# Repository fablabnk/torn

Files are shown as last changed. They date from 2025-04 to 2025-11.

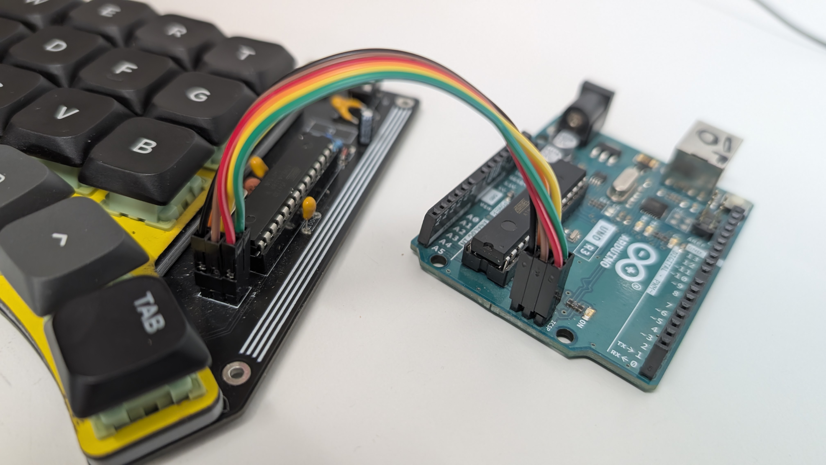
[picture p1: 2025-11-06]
TornFlashGuideICSPPins.jpg

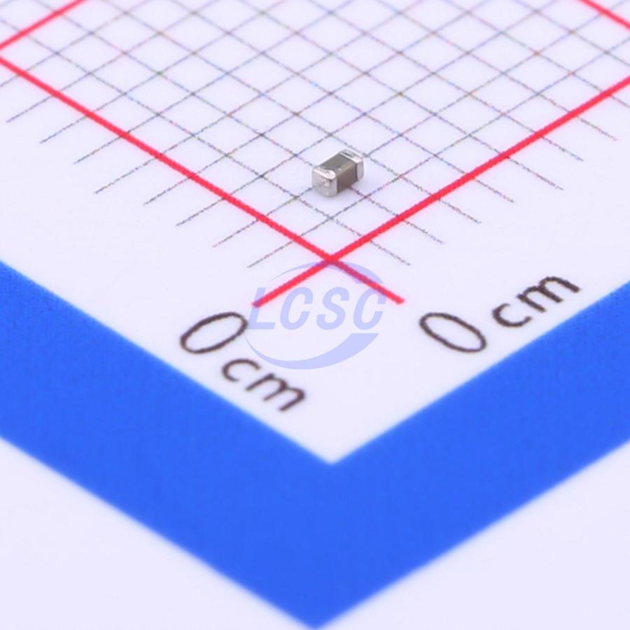
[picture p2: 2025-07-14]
notes/DIYKeyboardPCBA/JLCPCB PCBA Viewer_files/20221230_Samsung-Electro-Mechanics-CL05A105KA5NQNC_C5292_002.jpg

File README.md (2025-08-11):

This is the 42 Berlin fork of the original torn v3 project. We would like to make this project available to anyone in the school who has interest, but first we want to reliably be able to build the project and document any extra steps here.

# Project Status

- Both sides of the keyboard work and can be configured using QMKVia
- Waiting on new PCBs (USB Mini)
- QMKVia flashed (instead of previously just QMK default without Via)

# Next Steps

## Assemble one of the new just Urs and I
- 28th July
- document any remaining issues

## Open project for more people to get involved (at Teatime event Aug 13th)
	- leave the prototype keyboard in cafe and showcase at teatime event on 13th August
	- people can register to the projet via google form
	- order parts and PCBs based on number of registrations
	- set build day (or two days)

## Hosting 'workshop' where we build three or four more

one big day - or a couple of 3 or 4 hour events
deadline

0. Introduction to custom keyboards
- do we have a keyboard 'nerd' we could reach out to and include in the group?
1. Soldering
- solder everything or focus on microcontroller/display first
2. Flashing QMK/Via
- keep dedicated flashing setup on hand
- note that this was done by the previous group so we need to figure out how it works and documents
3. Configuration
- 
4. Case

# To Do

- Get LEDs working - LEDs are apparently not configured in the current QMK firmware
	- Define the correct pin assignments for the LEDs in config.h.
	- Implement the appropriate LED control functions in your keymap or keyboard .c file, such as led_set_user() for lock indicators or custom code for other uses.

- Solve display glitching issue
	- probably hardware related as we tested with another half which doesn't glitch

- add this line to build-guide.md
	- In order to call 'make' the qmk cli has to be installed. Follow the instructions [here](https://docs.qmk.fm/newbs_getting_started).

- Make one default layout that everyone gets at the beginning

# Documented Issues

## Flashing the Bootloader

We have an Arduino set aside in a box to help with flashing the bootloader
The original guide has the right instructions in terms of pinouts, but it's easy to the wiring up, so for 2nd build we should to document better how to wire the pins to the 6-pin header on the keyboard (photo)

## Flashing the Firmware

There were two issues here that diverged from the build guide. We installed all the necessary dependencies and tools in the LabAdmin account on the computer on the left next to the window.

- QMKVia which torn v3 uses is no longer supported. We don't have a solution for this, as the support for it its dropped and requires manual intervention and investigation as mentioned in the author isse https://github.com/rtitmuss/torn/issues/29

- The make command to be run from the qmk_firmware folder is ```make torn:default:flash``` as opposed to the guide. Keyboard must be set to flashing mode.

## Layout Configuration

- A C file is used to configure the keyboard [keymap file](https://github.com/qmk/qmk_firmware/blob/master/keyboards/torn/keymaps/default/keymap.c). This could be improved by adding a wrapper. Any alterations require compiling and flashing to the chip, which could complicate things though

## Button Height

The choice of height of the two reset/boot buttons is important. For the first build we used very flat buttons, only later to discover that they are inaccessible when adding the transparent acrylic layer on top. The solution to this would be to use taller buttons (we have them in different sizes in a kit) and to cut holes in the acrylic layer to allow the buttons to poke through.

## Choice of Case

It helps to consider which case you might build even from the get-go, as it can affect which buttons you choose (see below) and for some cases the switches/keycaps need to be of a certain type.

What we tried to far:
- PCB Case: We noted that there are no .svg files provided for laser cutting the parts, we must create our own from the Kicad projects (base and plate). This requires a few design decisions (indent around USB connector etc)
- HiPro Case: Be aware that there are two variations here for MX or Choc switches

# FAQ

## What is VIA and how does it work?

VIA is a software tool that allows you to dynamically remap keys and configure your keyboard layout in real time—without needing to reflash the firmware each time you want to make a change. Carlo and co didn't get this to work and filed this issue: https://github.com/rtitmuss/torn/issues/29

- Keys are organised in categories - can be character or functions
- Layers at Tip Left
- Keys show both click and hold functions
- If Via doesn't provide the functionality you need, you can alway use QMK syntax by using the "Any" wildcard key, which lets you hardcode QMK keycode e.g. LT(2, KC_DEL) which when holding delete will put you in layer 2
- Here is a basic (cheat sheet)[https://docs.qmk.fm/keycodes_basic] for QMK keycodes

One issue we had is how to flash QMKVia, as:
- VIA keymaps are no longer held in the main QMK git repository.
- You will need to either compile a default one, write your own one, or follow the instructions to add the VIA userspace repository.
- See https://docs.qmk.fm/ChangeLog/20240526#migration-of-via-keymaps-to-via-team-control

## What firmware is running on the keyboard now?

QMK default

## How to flash QMK again in order to update the keyboard configuration?

See QMK section of torn build guide: https://github.com/rtitmuss/torn/blob/master/doc/build.md

## What are LEDs for and how to configure them?

Caps Lock, Num Lock, and Scroll Lock

## Are button row of keys even working?

In keymap.c, we can see the real function of these keys in the QWERTY layer
Left:	R_DEL,   KC_LCTL, S_BSPC,  R_DEL
Right:	G_ENT,   L_SPC,   KC_RALT, G_ENT

Note: don't trust keymap.c ASCII, configuration differs (so UP arrow being above DOWN)

Layers do work e.g.
- On left side of keyboard, 1st and 4th key R_DEL
	- performs delete when tapped
	- moves to RAISE layer when held
- On the right side of the keyboard, 2nd key L_SPC 
	- perform space when tapped
	- goes into lower mode when held 

Note: KC_TRNS or _______ means to look down to the next layer for the underlying function of the key

## What are rotary encoders typically used for?

- Scrolling (vertical or horizontal in documents/web pages)
- Undo/redo
- Zoom in/out
- Tab or window switching
- Launching macros or custom shortcuts.

# Remapping

This means editing the QMK keymap.c file within the QMK firmware and reflashing the firmware
https://github.com/qmk/qmk_firmware/blob/master/keyboards/torn/keymaps/default/keymap.c
- we don't want to do this right now!

https://github.com/qmk/qmk_firmware/tree/master/keyboards/torn

// https://github.com/rtitmuss/torn/issues/29

# Via Setup

# Setup your torn keyboard with via

## QMK Setup
 - Set up QMK Firmware including CLI like described [here](https://docs.qmk.fm/newbs_getting_started)
 - In order to get it running on linux I actually had to update my PATH varaiable accordingly (see  'Note on Debian, Ubuntu and their derivatives')

## get External QMK Userspace 
 - Instead of cloning the QMK-Firmware from the github, get the [QMK userspace via](https://github.com/the-via/qmk_userspace_via) repo and use it with the CLI instead.
 - I think one could also get the original firmware and change all the configs accordingly, however this one is already onfigured to work with VIA.

## Flash Torn 
 - Now inside the root folder, use the CLI to either compile:
 `qmk compile -kb torn -km via`
 or directly flash the updated keyboard firmware:
 `qmk flash -kb torn -km via`
 -> in order to flash, i usually have to reconnect the keyboard, wait until the oled shows 'TORN' and go into boot mode: like described [here](https://github.com/fablabnk/torn/blob/master/doc/build.md) in chapter QMK

## Configure using VIA 
 - After successfully flashing, I dis and reconnect the keyboard again and open the [via app](https://www.usevia.app/) in a chromium based browser or the Desktop app, which is available for download [here](https://github.com/the-via/releases/releases/)

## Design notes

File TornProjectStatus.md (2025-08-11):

# Next Steps: First Build of New PCB

With view to hosting a 'workshop' where we build three or four more

1. Soldering
	- take a 

	everything or focus on microcontroller/display first

2. Flashing
	- is flashing process documented
	- bootloader
	- firmware
	- keep dedicated flashing setup on hand
3. Configuration
	- Learning how to use Via
4. Casemaking	

Rotary encoders, primarily used for:
- Scrolling (vertical or horizontal in documents/web pages)
- Undo/redo
- Zoom in/out
- Tab or window switching
- Launching macros or custom shortcuts.

# How Does Via Work
- Keys are organised in categories - can be character or functions
- Layers at Tip Left
- Keys show both click and hold functions

# Next Steps
- meet again at 17:30
- goal to decide on a clear way for configuring the keyboard
- assemble one just Urs and I
- open project for more people to get involved
	- leave the prototype keyboard in cafe and showcase at teatime event on 13th August
	- people can register to the projet via google form
	- order parts and PCBs based on number of registrations
	- set build day (or two days)

# Status
- Two halves basically work
- Display glitches
- Main top three rows of keys work on each side
- Bottom function keys are not properly working
- USB C connector is a pain to solder (considering rolling back to usb mini)

# To Do

- Get LEDs working - LEDs are apparently not configured in the current QMK firmware
	- Define the correct pin assignments for the LEDs in config.h.
	- Implement the appropriate LED control functions in your keymap or keyboard .c file, such as led_set_user() for lock indicators or custom code for other uses.

- Solve display glitching issue
	- probably hardware related as we tested with another half which doesn't glitch

- Add this line to build-guide.md
	- In order to call 'make' the qmk cli has to be installed. Follow the instructions [here](https://docs.qmk.fm/newbs_getting_started).

- Understand why it doesn't (always) connect straight away or wake from sleep - hardware or software issue?

# Questions

## What is VIA?

VIA is a software tool that allows you to dynamically remap keys and configure your keyboard layout in real time—without needing to reflash the firmware each time you want to make a change. Carlo and co didn't get this to work and filed this issue: https://github.com/rtitmuss/torn/issues/29

Issue is that:
- VIA keymaps are no longer held in the main QMK git repository.
- You will need to either compile a default one, write your own one, or follow the instructions to add the VIA userspace repository.
- See https://docs.qmk.fm/ChangeLog/20240526#migration-of-via-keymaps-to-via-team-control

## What firmware is running on the keyboard now?

QMK default

## How to flash QMK again in order to update the keyboard configuration?

See QMK section of torn build guide: https://github.com/rtitmuss/torn/blob/master/doc/build.md

## What are LEDs for and how to configure them?

Caps Lock, Num Lock, and Scroll Lock

## Are button row of keys even working?

In keymap.c, we can see the real function of these keys in the QWERTY layer
Left:	R_DEL,   KC_LCTL, S_BSPC,  R_DEL
Right:	G_ENT,   L_SPC,   KC_RALT, G_ENT

Note: don't trust keymap.c ASCII, configuration differs (so UP arrow being above DOWN)

Layers do work e.g.
- On left side of keyboard, 1st and 4th key R_DEL
	- performs delete when tapped
	- moves to RAISE layer when held
- On the right side of the keyboard, 2nd key L_SPC 
	- perform space when tapped
	- goes into lower mode when held 

Note: KC_TRNS or _______ means to look down to the next layer for the underlying function of the key

# Remapping

This means editing the QMK keymap.c file within the QMK firmware and reflashing the firmware
https://github.com/qmk/qmk_firmware/blob/master/keyboards/torn/keymaps/default/keymap.c
- we don't want to do this right now!

#

https://github.com/qmk/qmk_firmware/tree/master/keyboards/torn

// https://github.com/rtitmuss/torn/issues/29

# Via Setup

# Setup your torn keyboard with via

## QMK Setup
 - Set up QMK Firmware including CLI like described [here](https://docs.qmk.fm/newbs_getting_started)
 - In order to get it running on linux I actually had to update my PATH varaiable accordingly (see  'Note on Debian, Ubuntu and their derivatives')

## get External QMK Userspace 
 - Instead of cloning the QMK-Firmware from the github, get the [QMK userspace via](https://github.com/the-via/qmk_userspace_via) repo and use it with the CLI instead.
 - I think one could also get the original firmware and change all the configs accordingly, however this one is already onfigured to work with VIA.

## Flash Torn 
 - Now inside the root folder, use the CLI to either compile:
 `qmk compile -kb torn -km via`
 or directly flash the updated keyboard firmware:
 `qmk flash -kb torn -km via`
 -> in order to flash, i usually have to reconnect the keyboard, wait until the oled shows 'TORN' and go into boot mode: like described [here](https://github.com/fablabnk/torn/blob/master/doc/build.md) in chapter QMK

## Configure using VIA 
 - After successfully flashing, I dis and reconnect the keyboard again and open the [via app](https://www.usevia.app/) in a chromium based browser or the Desktop app, which is available for download [here](https://github.com/the-via/releases/releases/)

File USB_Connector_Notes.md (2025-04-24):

I want to replace the original 16-pin USB C connector with a mini USB connector

https://www.aliexpress.com/item/1005005298166566.html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

USB_C_GCT_USB4085-Type-C 16 pin Female Connector

A1	GND	Ground
A4	VBUS	Power (5V)
A5	CC1	Configuration Channel 1
A6	D+	USB 2.0 Data+
A7	D-	USB 2.0 Data-
A8	SBU1	Sideband Use 1
A9	VBUS	Power (5V)
A12	GND	Ground
B1	GND	Ground
B4	VBUS	Power (5V)
B5	CC2	Configuration Channel 2
B6	D+	USB 2.0 Data+
B7	D-	USB 2.0 Data-
B8	SBU2	Sideband Use 2
B9	VBUS	Power (5V)
B12	GND	Ground

Mini USB Type B 5-Pin Female Connector

1	VCC	+5VDC Power
2	D-	Data Negative
3	D+	Data Positive
4	ID	Identification (often not connected)
5	GND	Ground

1 3 5
 2 4

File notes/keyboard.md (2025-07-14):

corne cherry v3 bom

# Components Assembled by JLCPCB

42 x D3_SMD_v2 SMD diodes
12 x LED_WS2812B_PLCC4_5.0x5.0mm_P3.2mm
42 x SK6812MINI-E LED
2 x Reset switches - https://www.digikey.com/en/products/detail/c-k/PTS636-SP43-LFS/10071717
Kailh or Mill-Max Hotswap Sockets - guessing

# Components to Self-solder/Install

40 x CherryMX_Hotswap switches (for normal keys)
2 x CherryMX_Hotswap_1.5u switches (for the two larger keys)
2 x MJ-4PP-9 TRS jacks
2 x OLEDs - what kind?
2 x Sparkfun ProMicro V3 microcontrollers
2 x battery packs

Cherry MX Hotswap switches do not need to be soldered to a PCB. Hotswap PCBs are designed to allow switches to be inserted and removed without soldering, thanks to the use of hotswap sockets like Kailh or Mill-Max. These sockets have spring-loaded contacts that make electrical connections with the switch pins when inserted, allowing for easy swapping of switches without the need for soldering

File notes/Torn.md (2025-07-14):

# Torn

Video of the build: https://www.youtube.com/watch?v=7WUTQ30Datw
Build log: https://github.com/rafaeldelboni/buildlogs/blob/main/torn-v3.md
The torn project (through hole corne keyboard): https://github.com/rtitmuss/torn

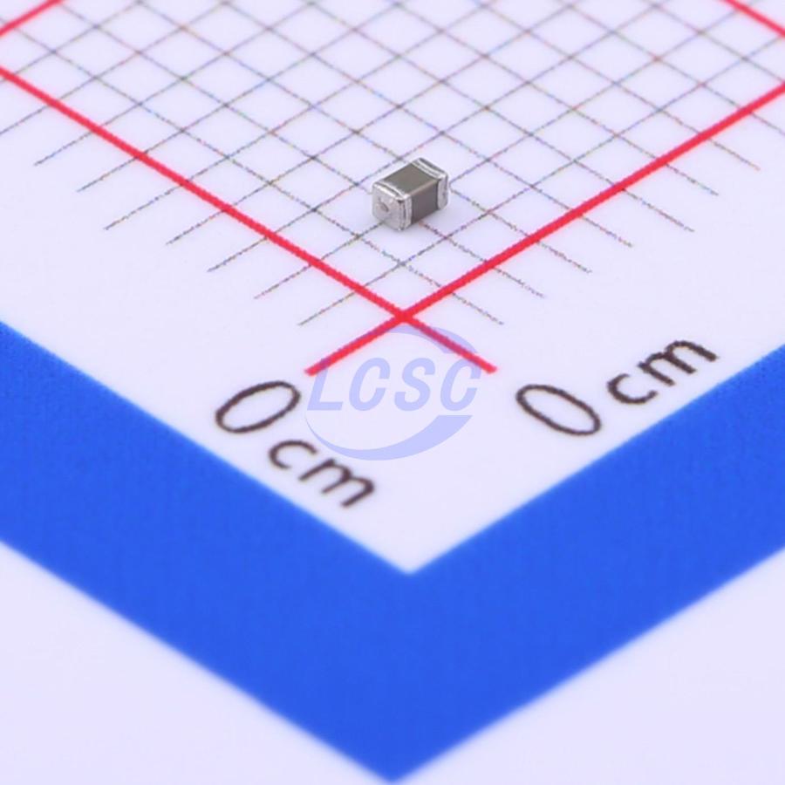
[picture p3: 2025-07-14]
notes/DIYKeyboardPCBA/JLCPCB PCBA Viewer_files/20220823_Samsung-Electro-Mechanics-CL05A106MQ5NUNC_C15525_fr.jpg

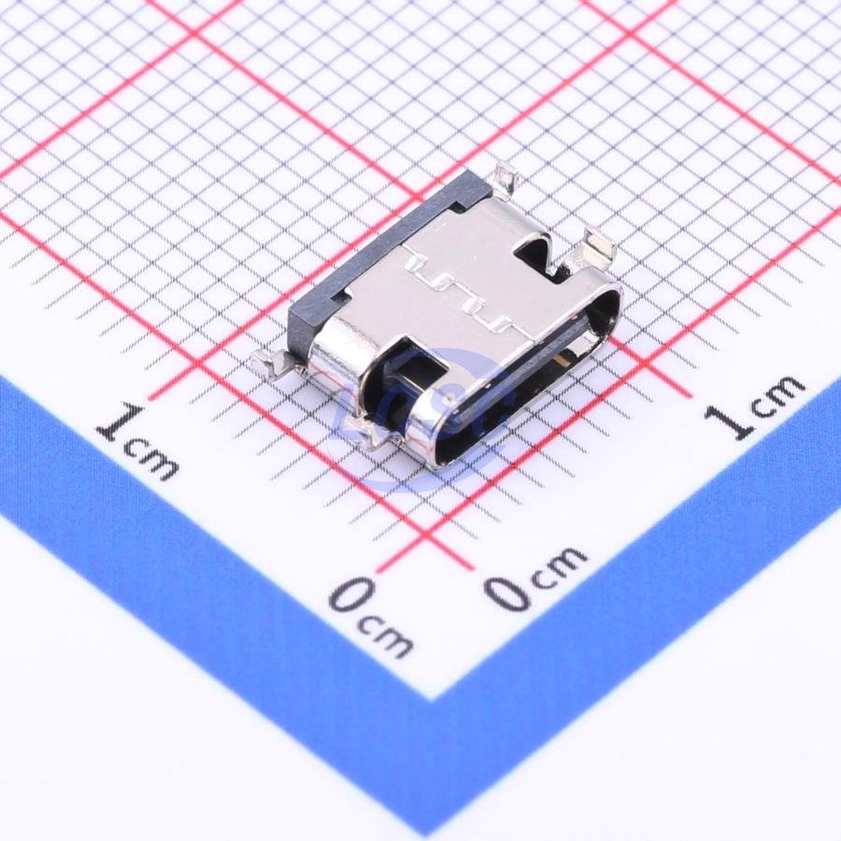
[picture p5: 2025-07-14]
notes/DIYKeyboardPCBA/JLCPCB PCBA Viewer_files/20230121_Korean-Hroparts-Elec-TYPE-C-31-M-13C_C2848620_front.jpg

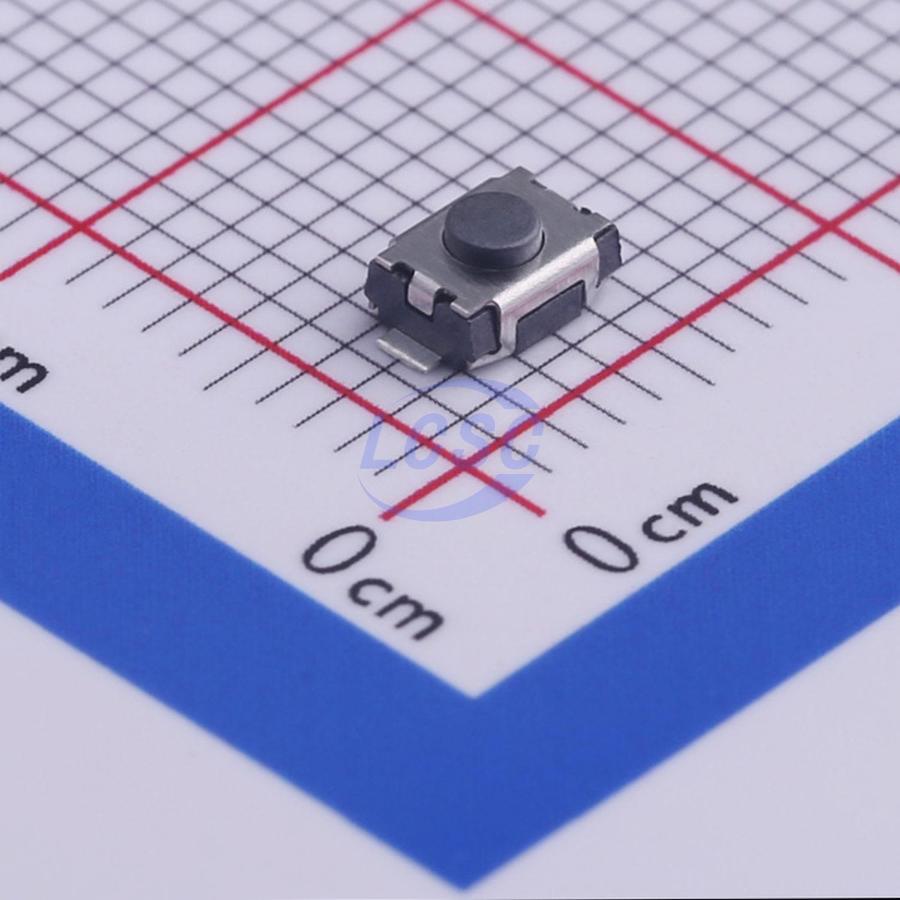
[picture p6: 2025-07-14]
notes/DIYKeyboardPCBA/JLCPCB PCBA Viewer_files/20230118_XUNPU-TS-1088R-02026_C455280_front.jpg

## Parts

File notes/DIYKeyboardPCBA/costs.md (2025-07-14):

Charge Details

    Engineering fee €3.64
    Board €10.27

Economic PCBA PriceSetup Fee €7.27

    Stencil  €1.36
    Components €10.15 (for each keyboard)
    Extended components fee ? €2.73 per Extended Component (of which we currently have 13 such parts)
    SMT Assembly ?

Shipping roughly €20

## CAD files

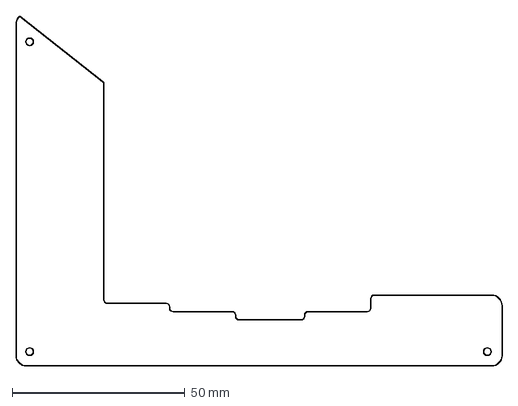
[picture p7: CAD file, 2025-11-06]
case/cover-1to1scale.dxf
140.7 x 101.3 mm

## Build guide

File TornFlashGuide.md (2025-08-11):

Note: maybe first step should be ATMEGA/crystal/caps as show here
https://github.com/rtitmuss/torn/blob/master/doc/bootloader.md

# ICSP header 

We use an Arduino Uno to flash the QMK/via firmware onto the ATMEGA328P chip mounted on the left half of the torn. To do this we connect together the ICSP header

An ICSP (In-Circuit Serial Programming) header is a standardized 6-pin interface on microcontroller boards used to program the microcontroller while it is installed in the circuit. It typically includes pins for power (VCC), ground (GND), reset, clock (SCK), and data lines (MISO and MOSI) for serial communication. 

The ICSP header on both the torn and the Uno is oriented in the same way. When USB ports are facing upwards, the pinout is as follows, where bottom right pin (2) is VCC/5V

https://mischianti.org/arduino-uno-rev-3-high-resolution-pinout-datasheet-and-specs/

5 3 1
6 4 2

The full list of connections is as follows:

ICSP Pin 1 (MISO)	→ ATmega328P Pin 18	(MISO)		COL4		
ICSP Pin 2 (VCC)	→ Power Supply		(5V)					RED
ICSP Pin 3 (SCK)	→ ATmega328P Pin 19	(SCK)		COL3		
ICSP Pin 4 (MOSI)	→ ATmega328P Pin 17	(MOSI)		COL5		
ICSP Pin 5 (RESET)	→ ATmega328P Pin 1	(RESET)					
ICSP Pin 6 (GND)	→ Ground			(GND)					BLACK

Original guide here: https://github.com/rtitmuss/torn/blob/master/doc/bootloader.md
- don't trust it - board is different - take own photos
- why do they not use the Reset pin on the ICSP header, and instead wire a separate connection to Pin 10 of the Uno?

- in short:

# Program the Uno as an In-circuit Serial Programmer (ISP)

// Follow https://www.arduino.cc/en/Tutorial/ArduinoISP#toc5 to program the whole flash memory of the microcontroller, bootloader included.

Skip the whole "How to wire your boards" section - this we will do with our torn later
Tools -> Burn Bootloader !?!?!
3. Tools -> Programmer -> "Arduino as ISP"

In Arduino IDE, select:
1. Tools -> Board -> Arduino Uno
2. Tools -> Port -> e.g. /tty/USB0
3. File -> Examples -> ArduinoISP -> ArduinoISP
4. Upload the sketch to the Uno
5. Connect an 10µF electrolytic capacitor between Arduino RESET and GND pins with the positive (long leg) connected to RESET
6. Connect pin 10 of Arduino to top left pin 5 of torn
7. Connect all other pins of torn ICSP header to their corresponding ICSP pins on the Uno
- Note that we don't need to power the keyboard via USB 
- Power to ATMEGA is provided by ICSP header 
7. Download https://github.com/rtitmuss/USBaspLoader, do `git switch torn` to switch to torn-specific branch 
- Edit Makefile.inc to point to /dev location of the Arduino Uno (check by `ls /dev` before and after connecting)
`PROGRAMMER = -c avrisp -P /dev/cu.usbmodem* -b19200`
In my case it needed to be:
`PROGRAMMER = -c avrisp -P /dev/ttyUSB0 -b19200` where usbtty0 is the item that appears in /dev when you connect your Uno via USB
The other change I saw that was made in torn branch is:
`DEVICE = atmega328p`  instead of atmega8
8. The next steps follow the flashing section of the bootloader guide here: https://github.com/rtitmuss/torn/blob/master/doc/bootloader.md#flashing
a. `make`
b. `make flash`

End result should be:
```
avrdude: 2176 bytes of flash verified
avrdude done.  Thank you.
```

c. `make fuse`

End result should be:
```
======>BUILDING BOOTLOADER FIRMWARE
.
make[1]: Entering directory '/home/grm/Desktop/USBaspLoader/firmware'
make[1]: Nothing to be done for 'all'.
make[1]: Leaving directory '/home/grm/Desktop/USBaspLoader/firmware'
make[1]: Entering directory '/home/grm/Desktop/USBaspLoader/firmware'
.
avrdude -c avrisp -P /dev/ttyUSB0 -b19200 -p atmega328p -U lfuse:w:0xd7:m -U hfuse:w:0xd0:m -U efuse:w:0xfc:m

avrdude: AVR device initialized and ready to accept instructions
avrdude: device signature = 0x1e950f (probably m328p)
avrdude: reading input file 0xd7 for lfuse
         with 1 byte in 1 section within [0, 0]
avrdude: writing 1 byte lfuse ...
avrdude: 1 byte of lfuse written
avrdude: verifying lfuse memory against 0xd7
avrdude: 1 byte of lfuse verified
avrdude: reading input file 0xd0 for hfuse
         with 1 byte in 1 section within [0, 0]
avrdude: writing 1 byte hfuse ...
avrdude: 1 byte of hfuse written
avrdude: verifying hfuse memory against 0xd0
avrdude: 1 byte of hfuse verified
avrdude: reading input file 0xfc for efuse
         with 1 byte in 1 section within [0, 0]
avrdude: writing 1 byte efuse ...
avrdude: 1 byte of efuse written
avrdude: verifying efuse memory against 0xfc
avrdude: 1 byte of efuse verified

avrdude done.  Thank you.

.
.
make[1]: Leaving directory '/home/grm/Desktop/USBaspLoader/firmware'
```

9. 
- Disconnect Arduino Uno ICSP header connections from torn and set aside
- perform `lsusb` in terminal, note what appears e.g.

```
Bus 001 Device 001: ID 1d6b:0002 Linux Foundation 2.0 root hub
Bus 001 Device 002: ID 04f3:0c8c Elan Microelectronics Corp. ELAN:ARM-M4
Bus 001 Device 003: ID 04f2:b7e8 Chicony Electronics Co., Ltd Integrated Camera
Bus 002 Device 001: ID 1d6b:0003 Linux Foundation 3.0 root hub
Bus 003 Device 001: ID 1d6b:0002 Linux Foundation 2.0 root hub
Bus 004 Device 001: ID 1d6b:0003 Linux Foundation 3.0 root hub
```

- Connect torn to PC via USB mini cable (ensure it's a data cable)
- Hold RESET button, hold BOOT button, release RESET button, release BOOT button
- perform `lsusb` again, this line should have appeared (be quick, it only appears very briefly!)

```
Bus 001 Device 018: ID 16c0:05dc Van Ooijen Technische Informatica shared ID for use with libusb
```
e.g.
```
Bus 001 Device 001: ID 1d6b:0002 Linux Foundation 2.0 root hub
Bus 001 Device 002: ID 04f3:0c8c Elan Microelectronics Corp. ELAN:ARM-M4
Bus 001 Device 003: ID 04f2:b7e8 Chicony Electronics Co., Ltd Integrated Camera
Bus 001 Device 018: ID 16c0:05dc Van Ooijen Technische Informatica shared ID for use with libusb
Bus 002 Device 001: ID 1d6b:0003 Linux Foundation 3.0 root hub
Bus 003 Device 001: ID 1d6b:0002 Linux Foundation 2.0 root hub
Bus 004 Device 001: ID 1d6b:0003 Linux Foundation 3.0 root hub
```

# Setup qmk/via

QMK or Quantum Mechanical Keyboard, is an open-source firmware for microcontrollers used in computer keyboards.
Via is needed to configure the keyboard from the browser

- setup/install qmk build environment in python virtual environment
- (source: https://docs.qmk.fm/newbs_getting_started)
`python3 -m venv venv`
`source venv/bin/activate`
`python3 -m pip install qmk`
`qmk setup` - answer yes to prompts
- in original build guide, it suggests to build from the 'torn' section of the official qmk repo (https://github.com/qmk/qmk_firmware) but we found that via doesn't work there 
- instead clone/build from the via repo instead
`git clone https://github.com/the-via/qmk_userspace_via`
`qmk compile -kb torn -km via`
`qmk flash -kb torn -km via`
- part way through you will see the message `Bootloader not found. Make sure the board is in bootloader mode.`. At this point on torn hold RESET button, then hold BOOT button, then release RESET button and finally release BOOT button
- Note: for me flashing failed part way through like below, until I changed USB port

```
avrdude: writing 21928 bytes flash ...

Writing | ################---------------------------------- | 32% 0.74s

avrdude error: error sending control message: Protocol error
avrdude error: error sending control message: No such device
avrdude error: wrong count at writing ffffffff
avrdude error: error sending control message: No such device
```
- Disconnect and reconnect keyboard, open the [via app](https://www.usevia.app/) in chromium-based browser or the Desktop app, which is available for download [here](https://github.com/the-via/releases/releases/)

- still having trouble pairing (maybe build/solder needs to continue to connect both keyboard halves)

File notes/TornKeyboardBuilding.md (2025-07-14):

# Keyboard Building

- Rotary encoder switch
- TRRS cable

# Order

add back in DuoRock switches
double number of DIP sockets
12.5MM encoders

# USB Connector

USB_C_GCT_USB4085-Type-C
https://www.mouser.com/ProductDetail/GCT/USB4085-GF-A?qs=KUoIvG%2F9Ilba1bQOahfWjw%3D%3D
vs
MC-668
https://www.aliexpress.com/item/1005004049841247.html?spm=a2g0o.cart.0.0.4d5738daLzJ8eA&mp=1

must check pinout will be the same

# TRRS Jack

https://beekeeb.com/lets-split-trrs-jack-alternatives/https://beekeeb.com/lets-split-trrs-jack-alternatives/

https://www.aliexpress.com/item/4001038550238.html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

PJ-324 PJ-324M and PJ3F07 are not good subs for SJ-43514 (3 conductor not 4)
https://www.mouser.de/datasheet/2/670/sj_4351x-1779303.pdf

PJ-320A is a good substitute but form factor is very different - consider redesigning for this!
https://evelta.com/content/datasheets/345-PJ-320A.pdf

is the height the same?!

TRRS

Keyboard Group
- vincent

SJ-43514 vs PJ-324M 

ATMEGA has bootloader or not

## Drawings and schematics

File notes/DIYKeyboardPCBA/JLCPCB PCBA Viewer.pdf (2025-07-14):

JLCPCB PCBA Viewer | https://jlcpcb.com/parts/bom-tool-res/?fileAccessId=9...

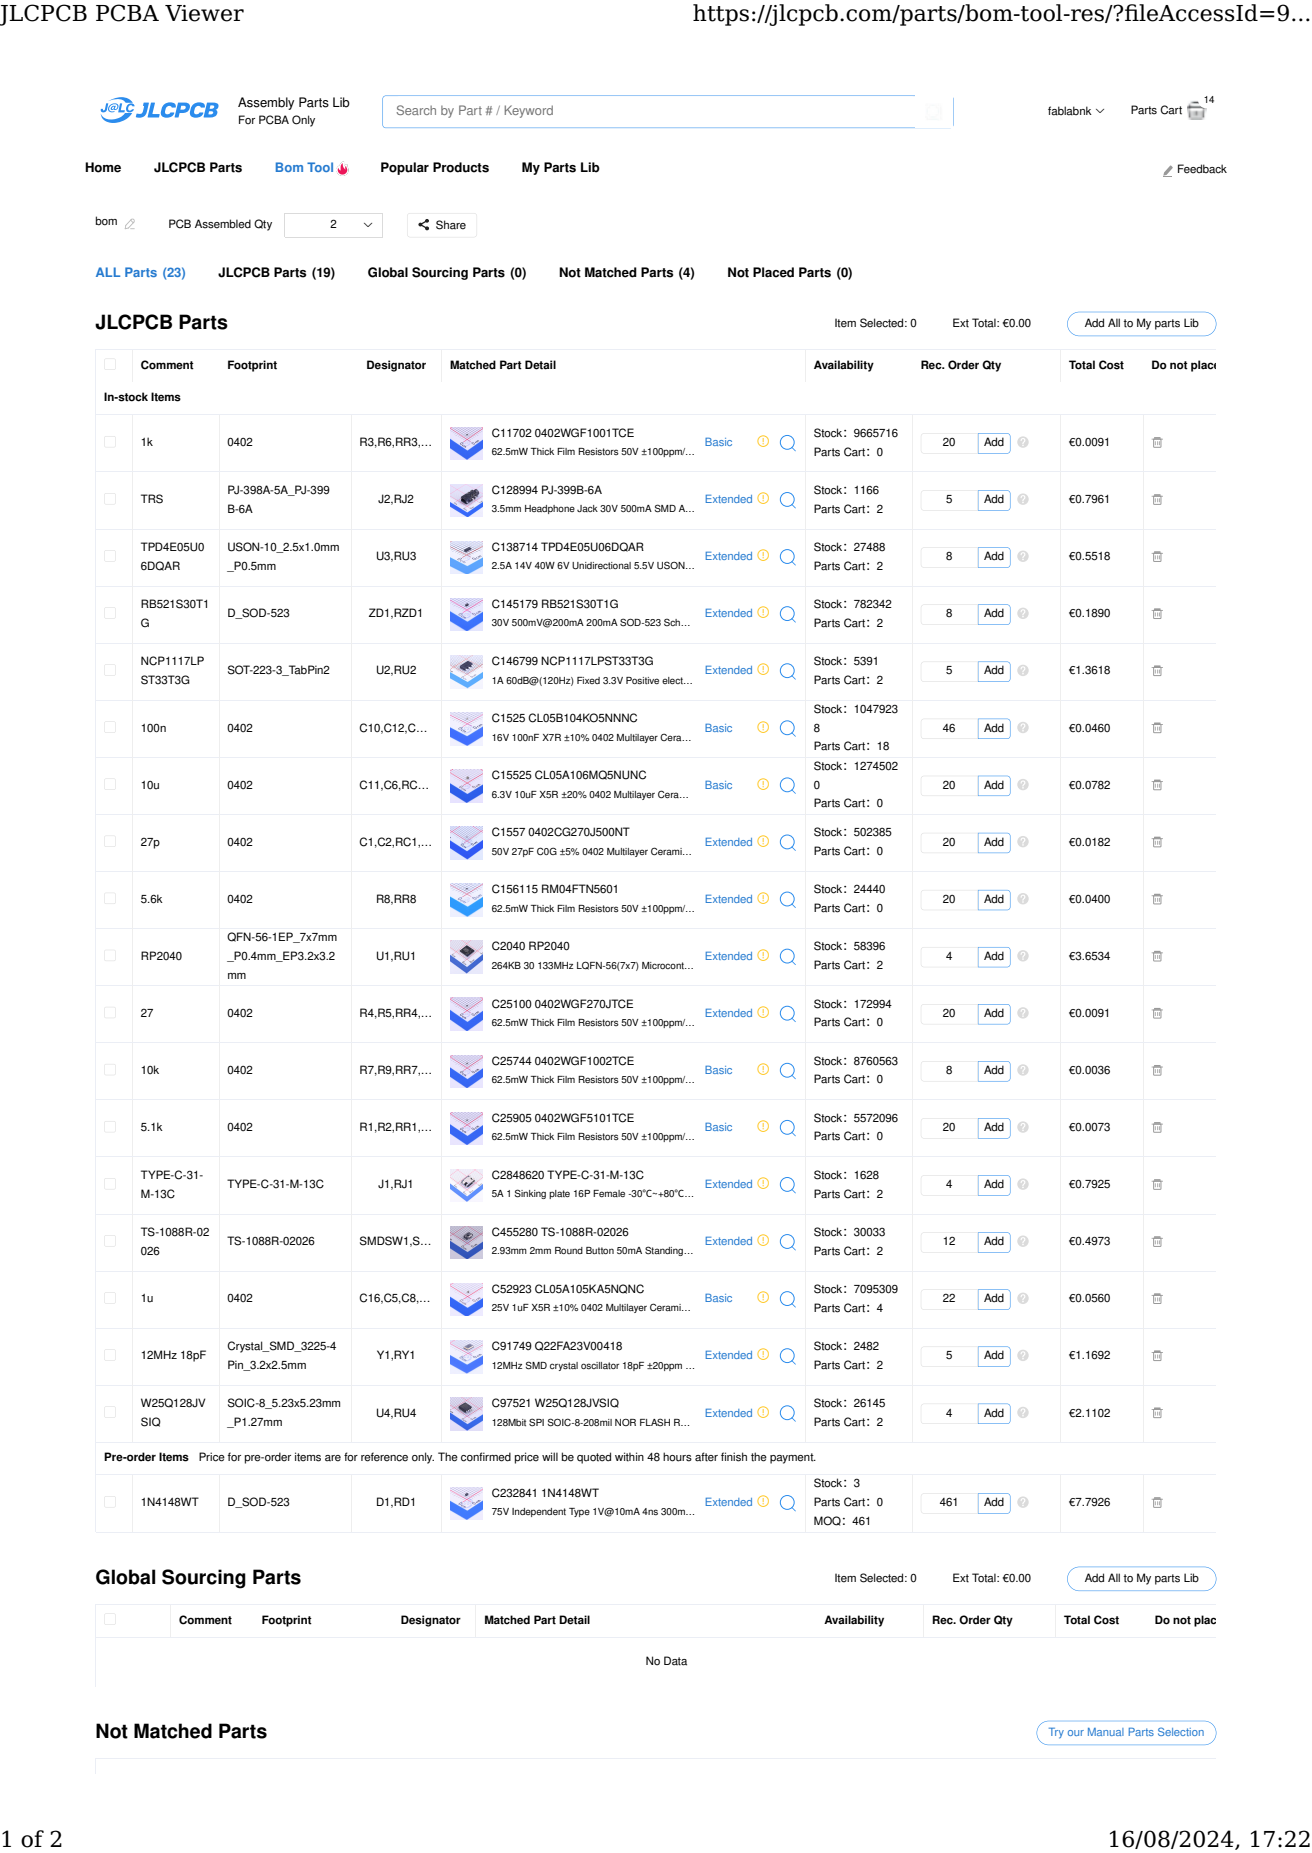
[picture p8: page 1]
Search by Part # / Keyword; fablabnk; Parts Cart; Feedback; bom; PCB Assembled Qty; Share; JLCPCB Parts; Item Selected: 0; Ext Total: €0.00; Add All to My parts Lib; Global Sourcing Parts; Not Matched Parts; Try our Manual Parts Selection; Comment; Footprint; Designator; Matched Part Detail; Availability; Rec. Order Qty; Total Cost; Do not place; C11702 0402WGF1001TCE; 62.5mW Thick Film Resistors 50V ±100ppm/… Basic; Stock：9665716; Parts Cart：0; Add; TRS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

Assembly Parts Lib
For PCBA Only

In-stock Items

Pre-order Items Price for pre-order items are for reference only. The confirmed price will be quoted within 48 hours after finish the payment.

75V Independent Type 1V@10mA 4ns 300m… Extended

Not Placed Parts | Place All Part
JLCPCB PCBA Viewer | https://jlcpcb.com/parts/bom-tool-res/?fileAccessId=9...

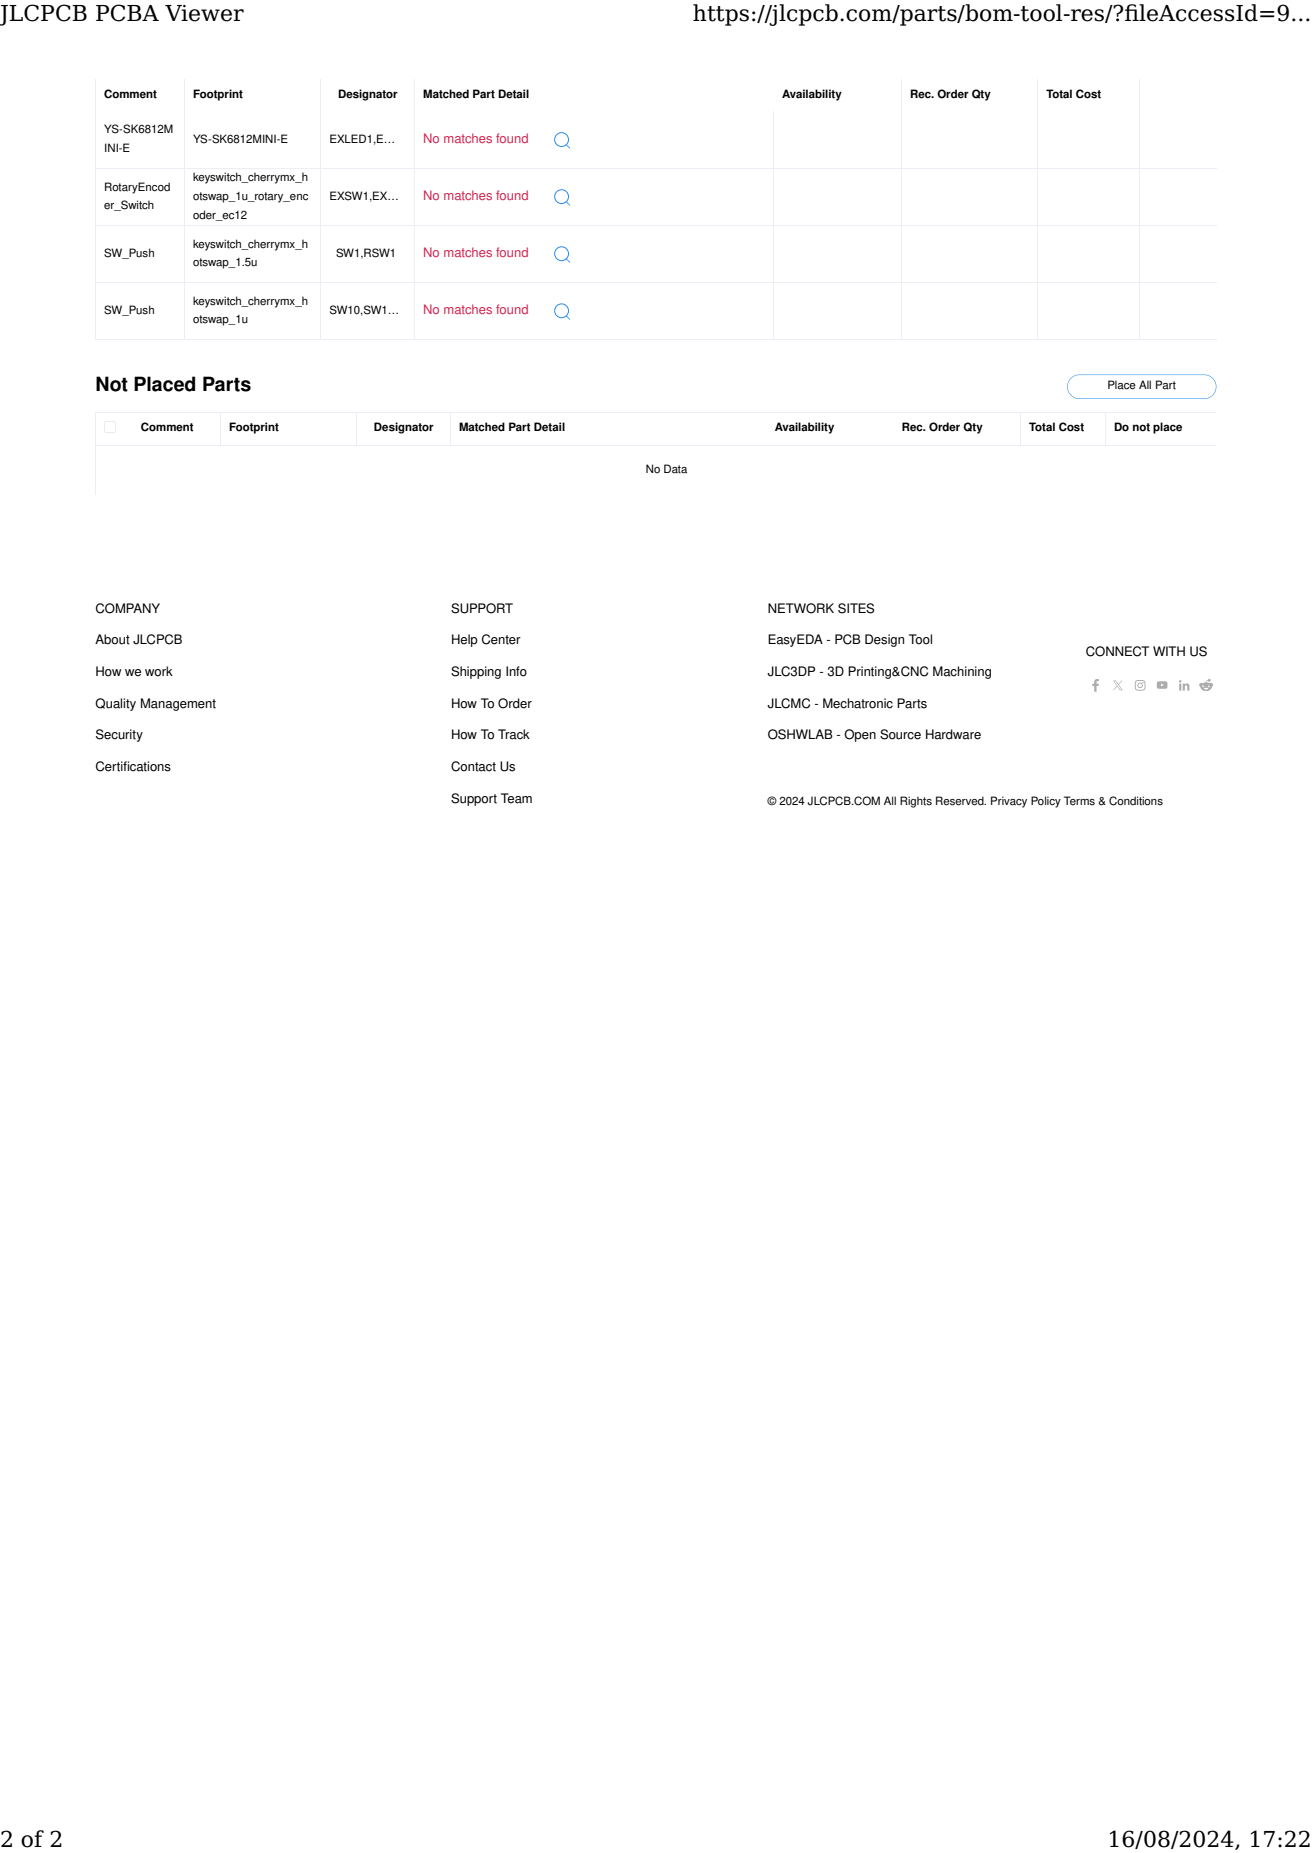
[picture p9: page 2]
COMPANY; About JLCPCB; Quality Management; Security; Certifications; SUPPORT; Help Center; Shipping Info; Contact Us; Support Team; NETWORK SITES; Comment; Footprint; Designator; Matched Part Detail; Availability; Rec. Order Qty; Total Cost; INI-E; YS-SK6812MINI-E; EXLED1,E…; No matches found; RotaryEncod; er_Switch; keyswitch_cherrymx_h; otswap_1u_rotary_enc; oder_ec12; EXSW1,EX…; SW_Push; otswap_1.5u; SW1,RSW1; otswap_1u; Do not place; No Data

EasyEDA - PCB Design Tool (https://easyeda.com/)

CONNECT WITH US

How we work (https://jlcpcb.com/aboutUs/howWorks)

JLC3DP - 3D Printing&CNC Machining (https://jlc3dp.com/?source=jlcpcb-footer)

How To Order (https://jlcpcb.com/help/catalog/11-How-To-Order)

JLCMC - Mechatronic Parts (https://jlcmc.com/?href=jlc-footer&source=jlc)

How To Track (https://jlcpcb.com/help/article/How-to-Track-My-Order)

OSHWLAB - Open Source Hardware (https://oshwlab.com/?source=jlcpcb-footer)

© 2024 JLCPCB.COM All Rights Reserved. Privacy Policy (https://jlcpcb.com/help/article/Privacy-Policy) Terms & Conditions (https://jlcpcb.com/help/article/Terms-%26-Conditions)

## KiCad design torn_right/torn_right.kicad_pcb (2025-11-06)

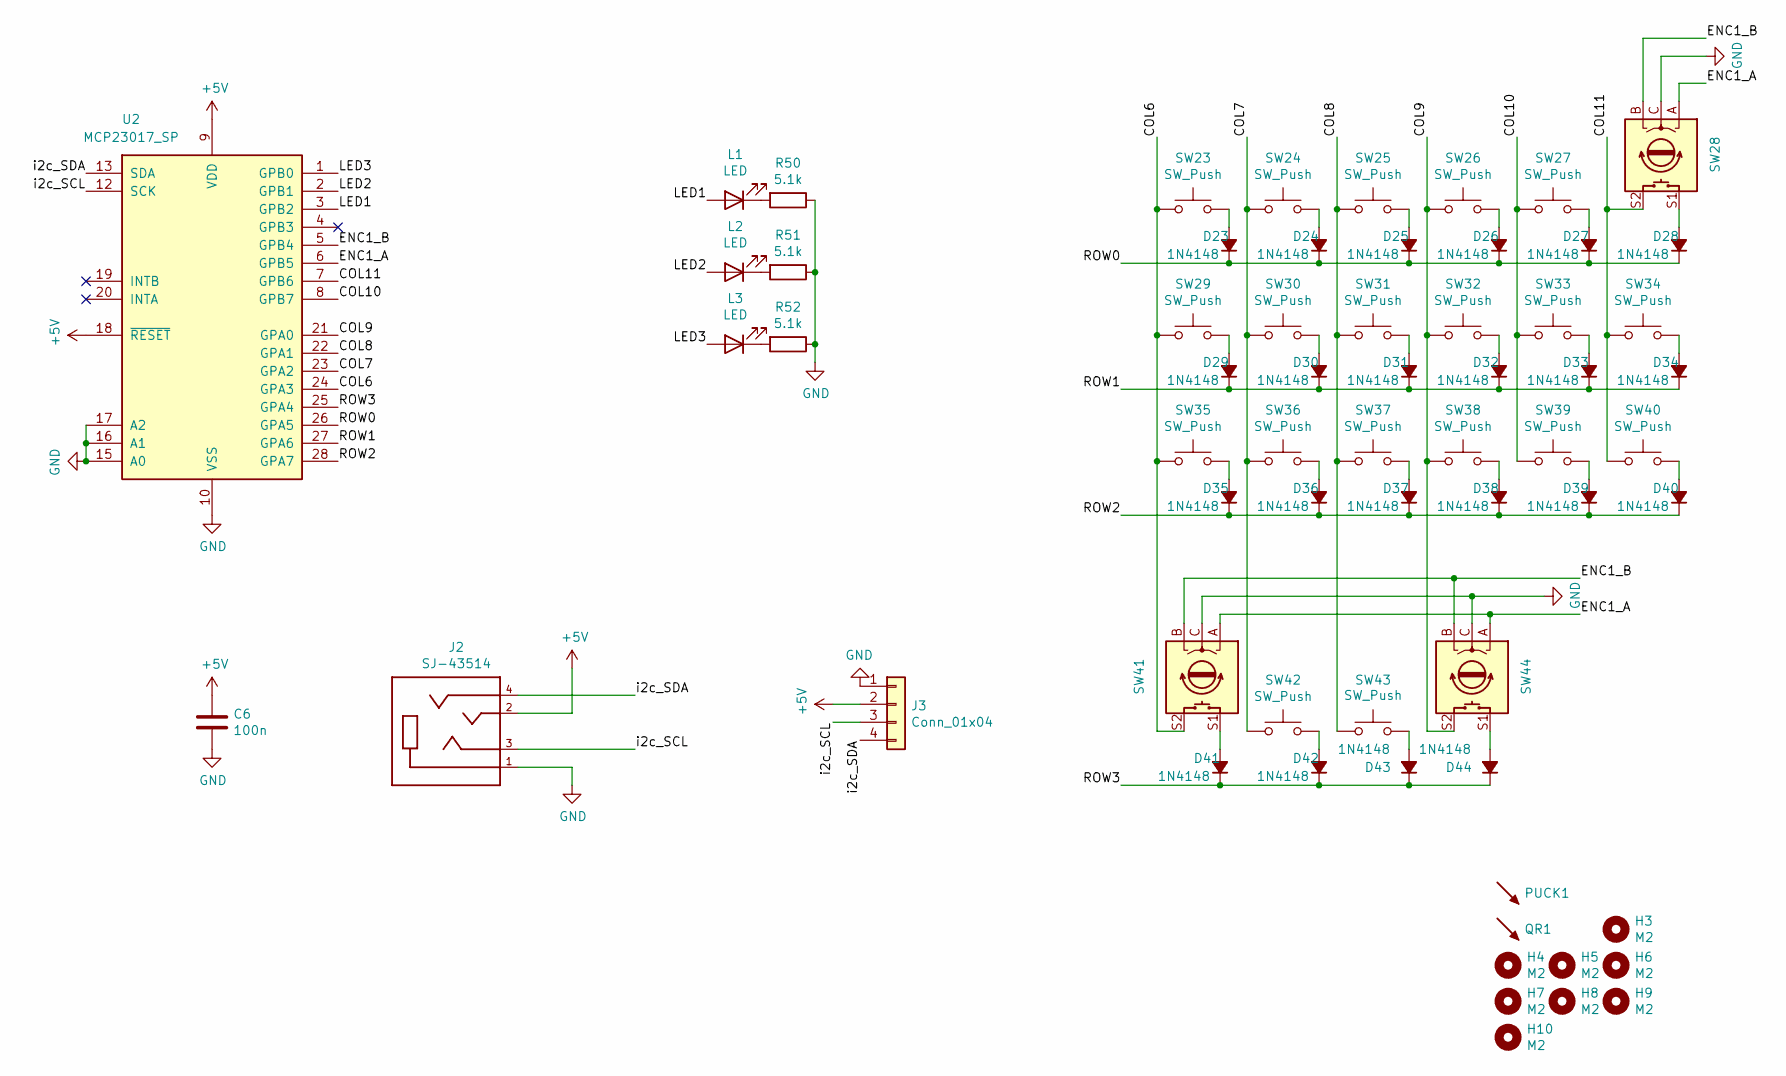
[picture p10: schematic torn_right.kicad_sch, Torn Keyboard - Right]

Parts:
C6: 100n; C_Disc_D4.3mm_W1.9mm_P5.00mm
D23, D24, D25, D26, D27, D28, D29, D30, D31, D32, D33, D34, D35, D36, D37, D38, D39, D40, D41, D42, D43, D44: 1N4148; D_DO-35_SOD27_P5.08mm_Horizontal
H3, H4, H5, H6, H7, H8, H9, H10: M2; MountingHole_2.2mm_M2_Pad
J2: SJ-43514; PJ-320A
J3: Conn_01x04; OLED_1side
L1, L2, L3: LED; LED_D3.0mm
PUCK1: PUCK; Tenting_Puck
QR1: SYM_Arrow45_Small; torn_qr_code
R50, R51, R52: 5.1k; R_Axial_DIN0207_L6.3mm_D2.5mm_P7.62mm_Horizontal
SW23, SW24, SW25, SW26, SW27, SW29, SW30, SW31, SW32, SW33, SW34, SW35, SW36, SW37, SW38, SW39, SW40, SW42, SW43: SW_Push; Kailh_socket_MX_PG1350_optional
SW28, SW41, SW44: Rotary_Encoder_Switch; Kailh_socket_MX_PG1350_EC11_optional
U2: MCP23017_SP; DIP-28_W7.62mm_Socket

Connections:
+5V: C6.1, J2.2, J3.2, U2.9 (VDD), U2.18 (~RESET)
/COL6: SW23.2, SW29.2, SW35.2, SW41.S2, U2.24 (GPA3)
/COL7: SW24.2, SW30.2, SW36.2, SW42.2, U2.23 (GPA2)
/COL8: SW25.2, SW31.2, SW37.2, SW43.2, U2.22 (GPA1)
/COL9: SW26.2, SW32.2, SW38.2, SW44.S2, U2.21 (GPA0)
/COL10: SW27.2, SW33.2, SW39.2, U2.8 (GPB7)
/COL11: SW28.S2, SW34.2, SW40.2, U2.7 (GPB6)
/ENC1_A: SW28.A, SW41.A, SW44.A, U2.6 (GPB5)
/ENC1_B: SW28.B, SW41.B, SW44.B, U2.5 (GPB4)
/LED1: L1.2 (A), U2.3 (GPB2)
/LED2: L2.2 (A), U2.2 (GPB1)
/LED3: L3.2 (A), U2.1 (GPB0)
/ROW0: D23.1 (K), D24.1 (K), D25.1 (K), D26.1 (K), D27.1 (K), D28.1 (K), U2.26 (GPA5)
/ROW1: D29.1 (K), D30.1 (K), D31.1 (K), D32.1 (K), D33.1 (K), D34.1 (K), U2.27 (GPA6)
/ROW2: D35.1 (K), D36.1 (K), D37.1 (K), D38.1 (K), D39.1 (K), D40.1 (K), U2.28 (GPA7)
/ROW3: D41.1 (K), D42.1 (K), D43.1 (K), D44.1 (K), U2.25 (GPA4)
/i2c_SCL: J2.3, J3.3, U2.12 (SCK)
/i2c_SDA: J2.4, J3.4, U2.13 (SDA)
GND: C6.2, J2.1, J3.1, R50.1, R51.1, R52.1, SW28.C, SW41.C, SW44.C, U2.10 (VSS), U2.15 (A0), U2.16 (A1), U2.17 (A2)
unnamed: D23.2 (A), SW23.1
unnamed: D24.2 (A), SW24.1
unnamed: D25.2 (A), SW25.1
unnamed: D26.2 (A), SW26.1
unnamed: D27.2 (A), SW27.1
unnamed: D28.2 (A), SW28.S1
unnamed: D29.2 (A), SW29.1
unnamed: D30.2 (A), SW30.1
unnamed: D31.2 (A), SW31.1
unnamed: D32.2 (A), SW32.1
unnamed: D33.2 (A), SW33.1
unnamed: D34.2 (A), SW34.1
unnamed: D35.2 (A), SW35.1
unnamed: D36.2 (A), SW36.1
unnamed: D37.2 (A), SW37.1
unnamed: D38.2 (A), SW38.1
unnamed: D39.2 (A), SW39.1
unnamed: D40.2 (A), SW40.1
unnamed: D41.2 (A), SW41.S1
unnamed: D42.2 (A), SW42.1
unnamed: D43.2 (A), SW43.1
unnamed: D44.2 (A), SW44.S1
unnamed: L1.1 (K), R50.2
unnamed: L2.1 (K), R51.2
unnamed: L3.1 (K), R52.2

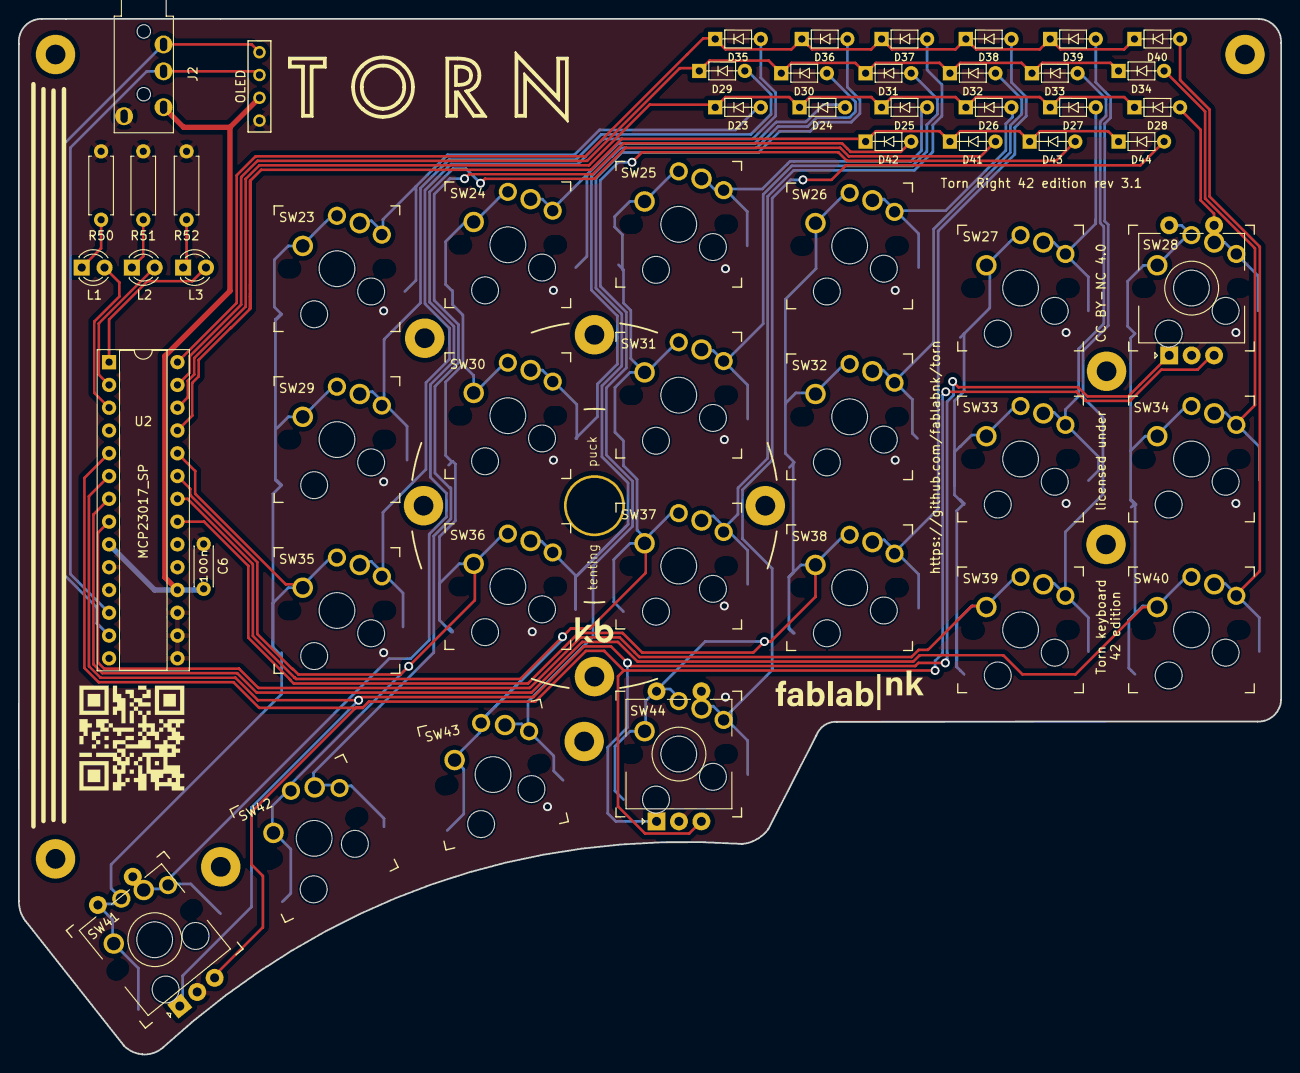
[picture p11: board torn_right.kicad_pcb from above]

Board: 2 copper layers, 140.7 x 115.4 mm, 64 parts (0 on the bottom side), 44 nets.

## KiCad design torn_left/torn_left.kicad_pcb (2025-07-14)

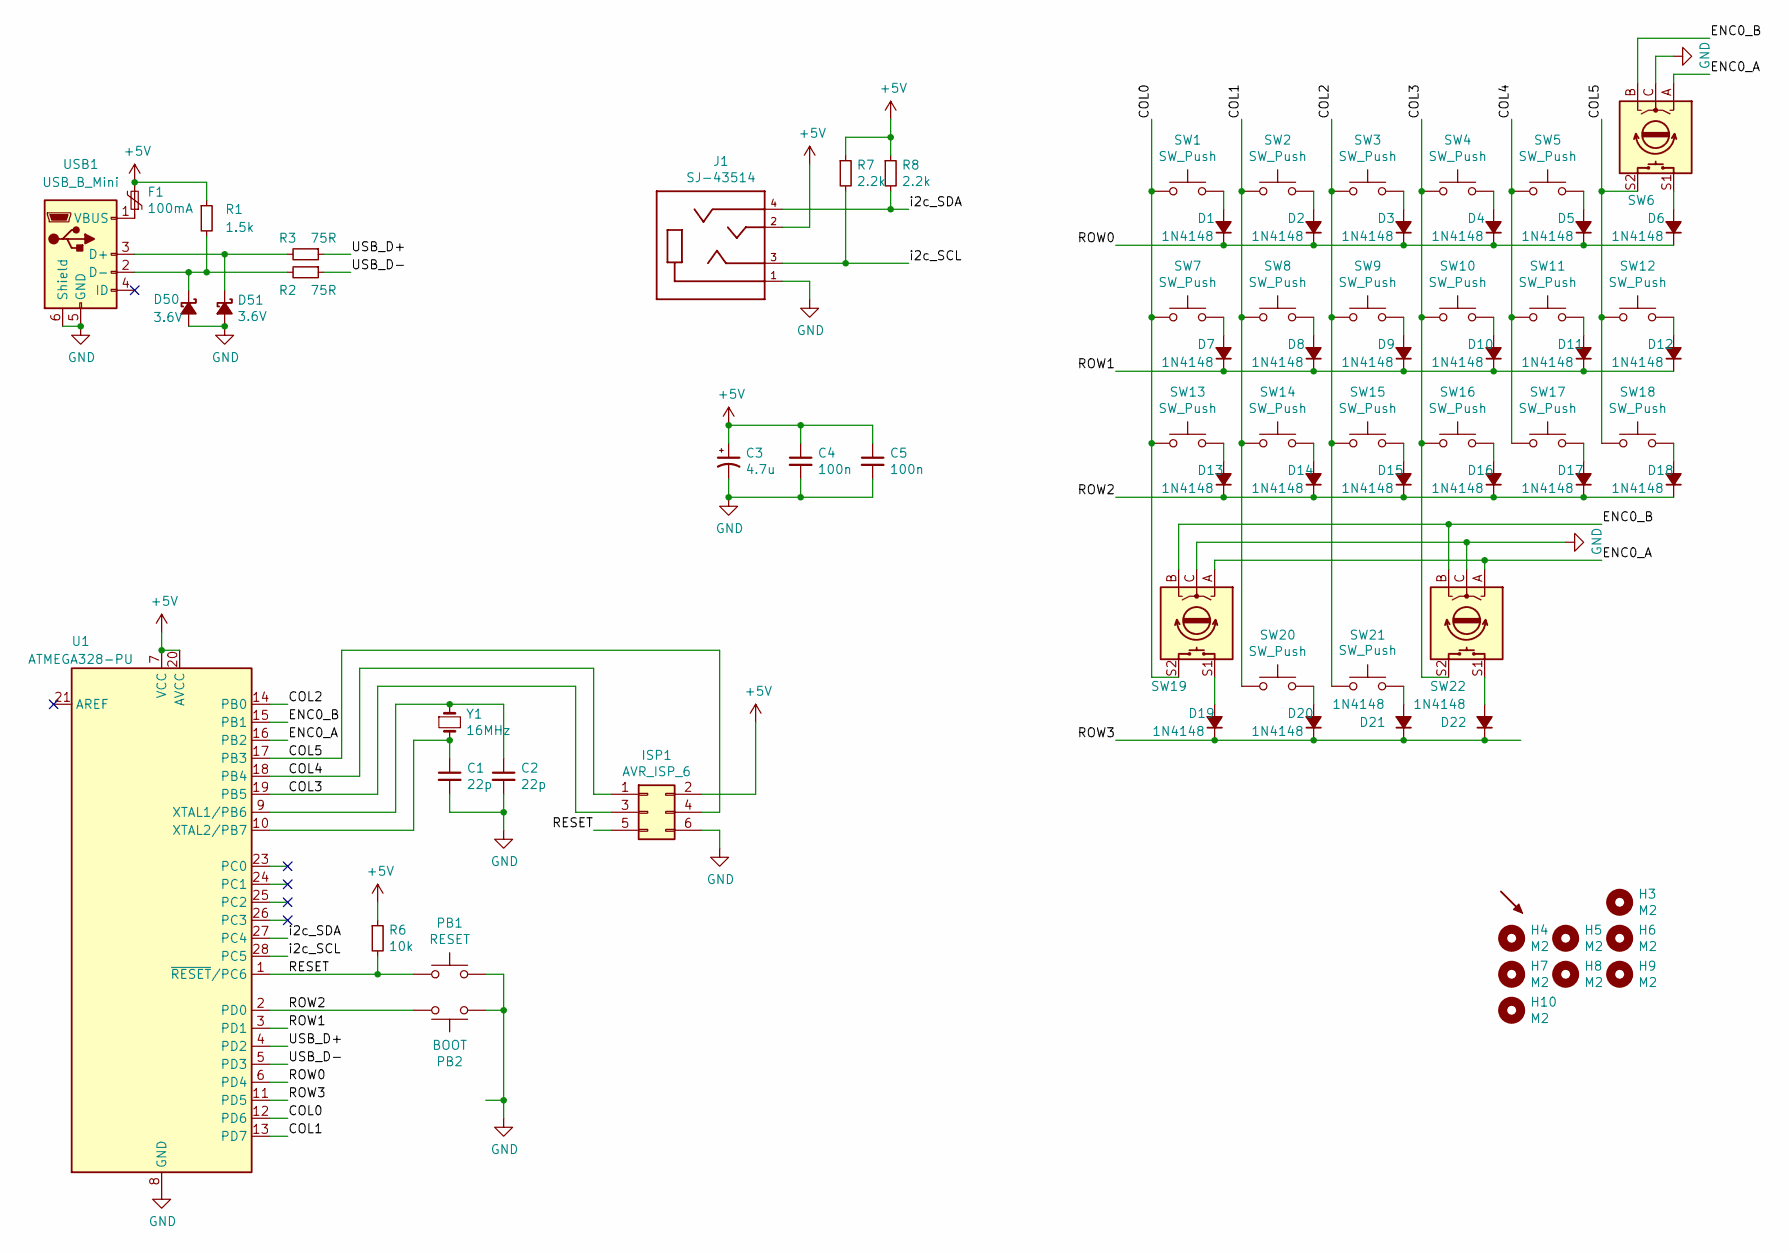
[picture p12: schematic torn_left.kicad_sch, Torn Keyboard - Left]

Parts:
C1, C2: 22p; C_Disc_D3.0mm_W1.6mm_P2.50mm
C3: 4.7u; CP_Radial_D4.0mm_P1.50mm
C4, C5: 100n; C_Disc_D4.3mm_W1.9mm_P5.00mm
D1, D2, D3, D4, D5, D6, D7, D8, D9, D10, D11, D12, D13, D14, D15, D16, D17, D18, D19, D20, D21, D22: 1N4148; D_DO-35_SOD27_P5.08mm_Horizontal
D50, D51: 3.6V; D_DO-35_SOD27_P5.08mm_Horizontal
F1: 100mA; polyfuse_5.1mm
H3, H4, H5, H6, H7, H8, H9, H10: M2; MountingHole_2.2mm_M2_Pad
ISP1: AVR_ISP_6; AVR_ICSP_3x2
J1: SJ-43514; PJ-320A
PB1: RESET; SW_PUSH_6mm
PB2: BOOT; SW_PUSH_6mm
PUCK1: SYM_Arrow45_Small; Tenting_Puck
R1: 1.5k; R_Axial_DIN0207_L6.3mm_D2.5mm_P7.62mm_Horizontal
R2, R3: 75R; R_Axial_DIN0207_L6.3mm_D2.5mm_P7.62mm_Horizontal
R6: 10k; R_Axial_DIN0207_L6.3mm_D2.5mm_P7.62mm_Horizontal
R7, R8: 2.2k; R_Axial_DIN0207_L6.3mm_D2.5mm_P7.62mm_Horizontal
SW1, SW2, SW3, SW4, SW5, SW7, SW8, SW9, SW10, SW11, SW12, SW13, SW14, SW15, SW16, SW17, SW18, SW20, SW21: SW_Push; Kailh_socket_MX_PG1350_optional
SW6, SW19, SW22: Rotary_Encoder_Switch; Kailh_socket_MX_PG1350_EC11_optional
U1: ATMEGA328-PU; DIP-28_W7.62mm_Socket
USB1: USB_B_Mini; USB-B-Mini-Right-Angled
Y1: 16MHz; Crystal_HC49-4H_Vertical

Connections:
+5V: C3.1, C4.1, C5.1, F1.2, ISP1.2, J1.2, R1.1, R6.1, R7.1, R8.1, U1.7 (VCC), U1.20 (AVCC)
/COL0: SW1.2, SW7.2, SW13.2, SW19.S2, U1.12 (PD6)
/COL1: SW2.2, SW8.2, SW14.2, SW20.2, U1.13 (PD7)
/COL2: SW3.2, SW9.2, SW15.2, SW21.2, U1.14 (PB0)
/COL3: ISP1.3, SW4.2, SW10.2, SW16.2, SW22.S2, U1.19 (PB5)
/COL4: ISP1.1, SW5.2, SW11.2, SW17.2, U1.18 (PB4)
/COL5: ISP1.4, SW6.S2, SW12.2, SW18.2, U1.17 (PB3)
/ENC0_A: SW6.A, SW19.A, SW22.A, U1.16 (PB2)
/ENC0_B: SW6.B, SW19.B, SW22.B, U1.15 (PB1)
/RESET: ISP1.5, PB1.1, R6.2, U1.1 (~RESET/PC6)
/ROW0: D1.1 (K), D2.1 (K), D3.1 (K), D4.1 (K), D5.1 (K), D6.1 (K), U1.6 (PD4)
/ROW1: D7.1 (K), D8.1 (K), D9.1 (K), D10.1 (K), D11.1 (K), D12.1 (K), U1.3 (PD1)
/ROW2: D13.1 (K), D14.1 (K), D15.1 (K), D16.1 (K), D17.1 (K), D18.1 (K), PB2.2, U1.2 (PD0)
/ROW3: D19.1 (K), D20.1 (K), D21.1 (K), D22.1 (K), U1.11 (PD5)
/USB_D+: R3.1, U1.4 (PD2)
/USB_D-: R2.1, U1.5 (PD3)
/i2c_SCL: J1.3, R7.2, U1.28 (PC5)
/i2c_SDA: J1.4, R8.2, U1.27 (PC4)
GND: C1.2, C2.2, C3.2, C4.2, C5.2, D50.2 (A), D51.2 (A), ISP1.6, J1.1, PB1.2, PB2.1, SW6.C, SW19.C, SW22.C, U1.8 (GND), U1.22 (GND), USB1.5 (GND), USB1.6 (Shield)
unnamed: D1.2 (A), SW1.1
unnamed: D2.2 (A), SW2.1
unnamed: D3.2 (A), SW3.1
unnamed: D4.2 (A), SW4.1
unnamed: D5.2 (A), SW5.1
unnamed: D6.2 (A), SW6.S1
unnamed: D7.2 (A), SW7.1
unnamed: D8.2 (A), SW8.1
unnamed: D9.2 (A), SW9.1
unnamed: D10.2 (A), SW10.1
unnamed: D11.2 (A), SW11.1
unnamed: D12.2 (A), SW12.1
unnamed: D13.2 (A), SW13.1
unnamed: D14.2 (A), SW14.1
unnamed: D15.2 (A), SW15.1
unnamed: D16.2 (A), SW16.1
unnamed: D17.2 (A), SW17.1
unnamed: D18.2 (A), SW18.1
unnamed: D19.2 (A), SW19.S1
unnamed: D20.2 (A), SW20.1
unnamed: D21.2 (A), SW21.1
unnamed: D22.2 (A), SW22.S1
unnamed: D50.1 (K), R1.2, R2.2, USB1.2 (D-)
unnamed: D51.1 (K), R3.2, USB1.3 (D+)
unnamed: C2.1, U1.9 (XTAL1/PB6), Y1.1
unnamed: C1.1, U1.10 (XTAL2/PB7), Y1.2
unnamed: F1.1, USB1.1 (VBUS)

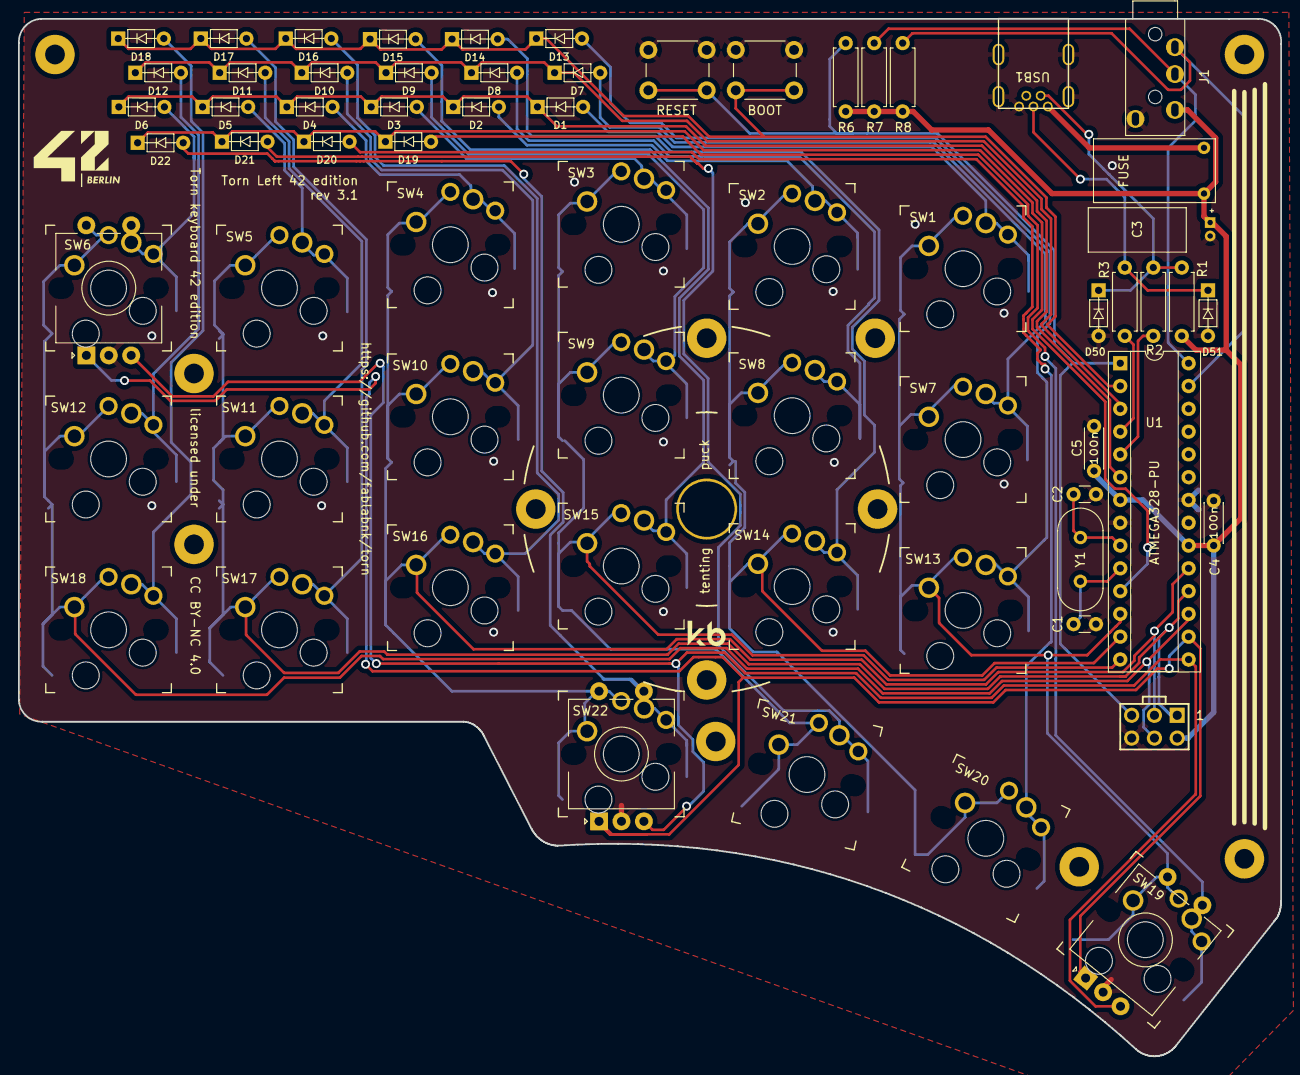
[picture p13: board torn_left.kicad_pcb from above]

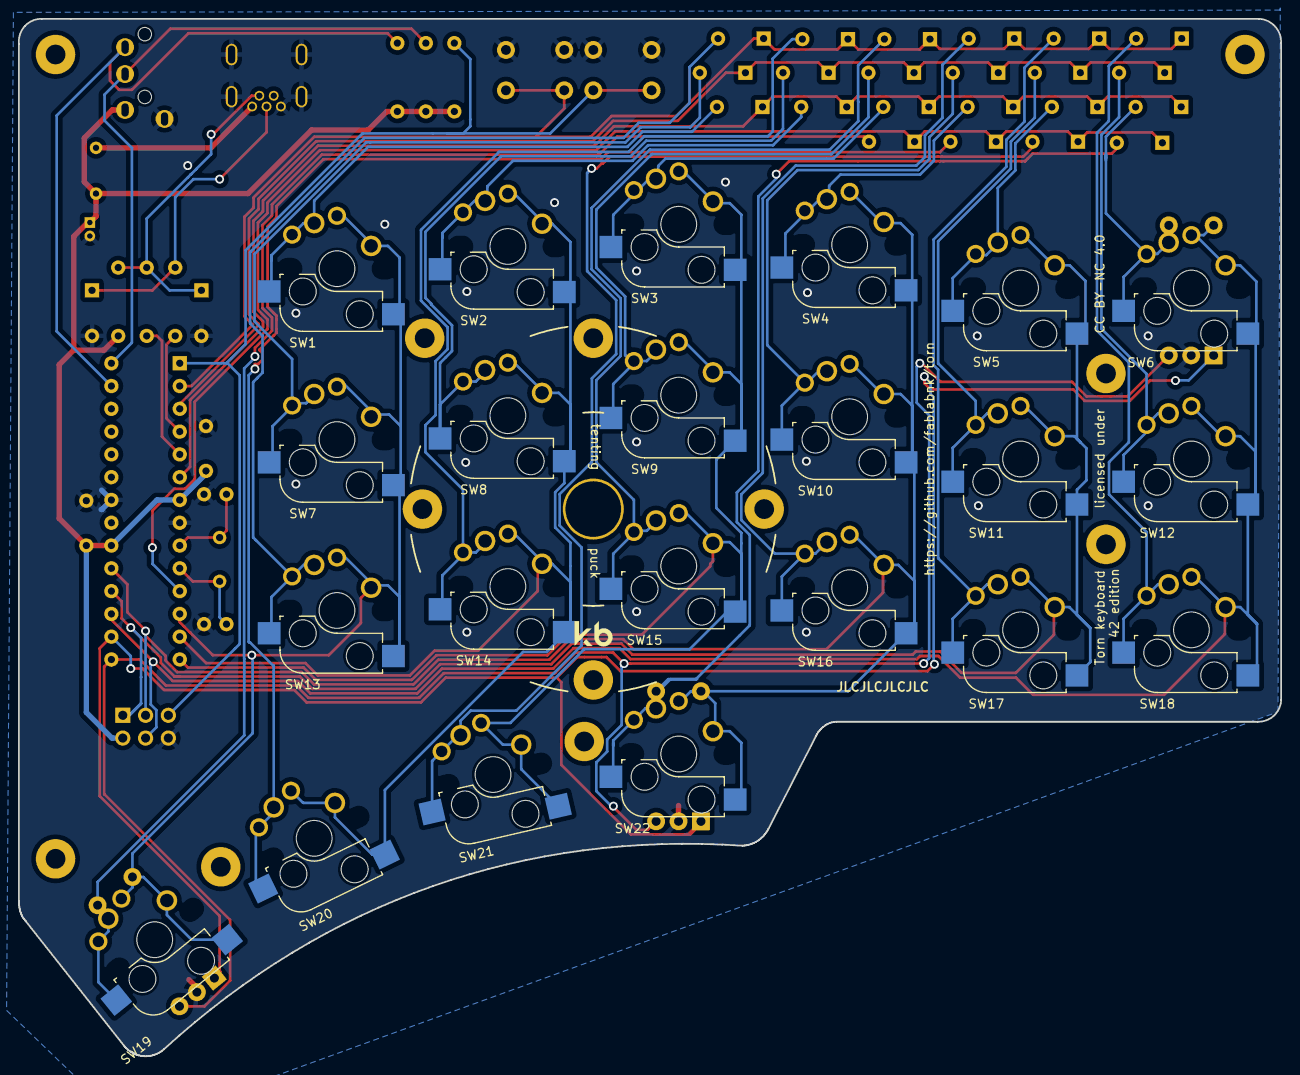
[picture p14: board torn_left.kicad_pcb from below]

Board: 2 copper layers, 140.7 x 115.6 mm, 74 parts (8 on the bottom side), 46 nets.

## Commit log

2025-04-24 preparing for new board revision
    [torn_left.kicad_pcb, torn_left.kicad_sch, torn_right.kicad_pcb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]
2025-07-14 committing before changing to standard size through hole resistors
    [torn_left.kicad_pcb, torn_right.kicad_pcb]
2025-07-14 changed resistor sizes to more common 1/4W 0207DIN sizes on both boards
    [torn_left.kicad_pcb, torn_left.kicad_sch, torn_right.kicad_pcb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]
2025-08-11 added TornFlashGuide.md documented how to flash bootloader using ArduinoISP and then firmware (including via)
2025-11-06 committing before switching out right hand TRRS connector
    [cover-1to1scale.dxf]
2025-11-06 right board updated with proper TRRS and other fixes - reminder to check left side passes DRC
    [torn_right.kicad_pcb, torn_right.kicad_sch]

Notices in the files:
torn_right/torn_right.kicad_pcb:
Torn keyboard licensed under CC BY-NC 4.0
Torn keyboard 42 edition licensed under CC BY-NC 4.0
